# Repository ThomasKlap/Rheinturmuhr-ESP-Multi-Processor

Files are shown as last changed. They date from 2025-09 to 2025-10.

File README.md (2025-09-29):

#  Rheinturmuhr (Lichtzeitpegel) Düsseldorf  

Lichtzeitpegel ist die Bezeichnung der Uhrenlichtskulptur des Künstlers Horst H. Baumann am Düsseldorfer Rheinturm. Sie wurde am 24. November 1981 in Betrieb genommen und ist gemäß dem Guinness-Buch der Rekorde die größte dezimale „Zeitskala“ der Welt. Die Uhr wird auch als Dezimaluhr bezeichnet, obwohl der „Lichtzeitpegel“ die klassische 24-Stunden-Uhrzeit anzeigt und die Ziffern im Unärsystem dargestellt werden.  
[Quelle: Wikipedia, [Lichtzeitpegel]( de.wikipedia.org/wiki/Lichtzeitpegel )] 

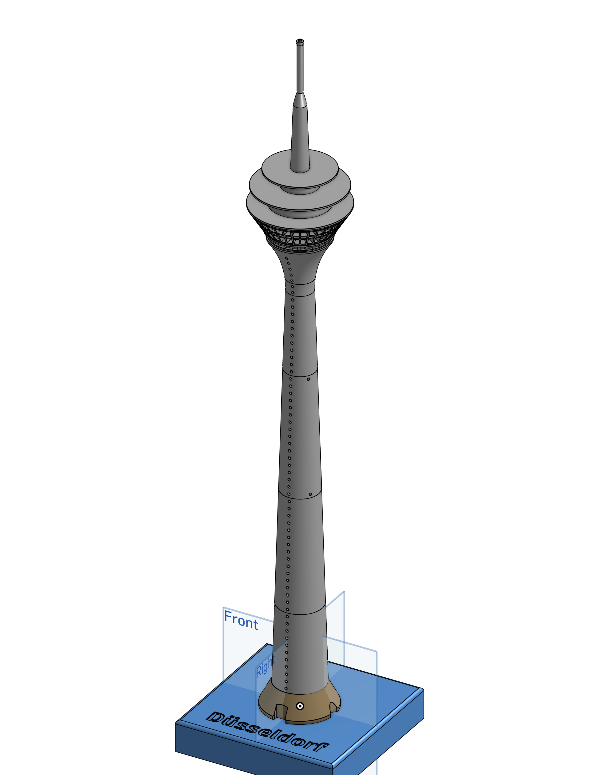
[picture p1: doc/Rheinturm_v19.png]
Bild


Die Bauteile, als .stl Files für den 3D Druck, liegen im Ordner Parts.  
Ich habe den Turm schon mehrfach in unterschiedlichen Farben PLA gedruckt.
Das Fenster oben im Restaurant sollte transparent gedruckt werden, da es von innen beleuchtet werden kann.
Zusätzlich zu den gedruckten Teilen wird eine Gewindestange M3x565 und zwei Gewindeeinsätze M3 benötigt, um den Turm zusammen zu halten.
Alternativ kann auch eine M4 Gewindestange direkt in die Kunststoffteile eingeschraubt werden.

Es wird ein 62 Elemente langer Neopixel Streifen, mit einer Dichte von 144px/m, verwendet.  
Dieser kann komplett in die Aufnahme innerhalb des Schaftes eingeführt werden.
Weitere Neopixel können oberhalb für das Restaurant verwendet werden.  
Die Positionsleuchten ringsum sind für 2mm Leds vorgesehen, welche dort eingeklebt werden.
Ich verwende für die Projekte einen Wemos D1mini mit ESP8266 Prozessor.  
Für den Anschluss wird ein 470 Ohm Widerstand empfohlen, um die Neopixel vor Spannungsspitzen zu schützen.

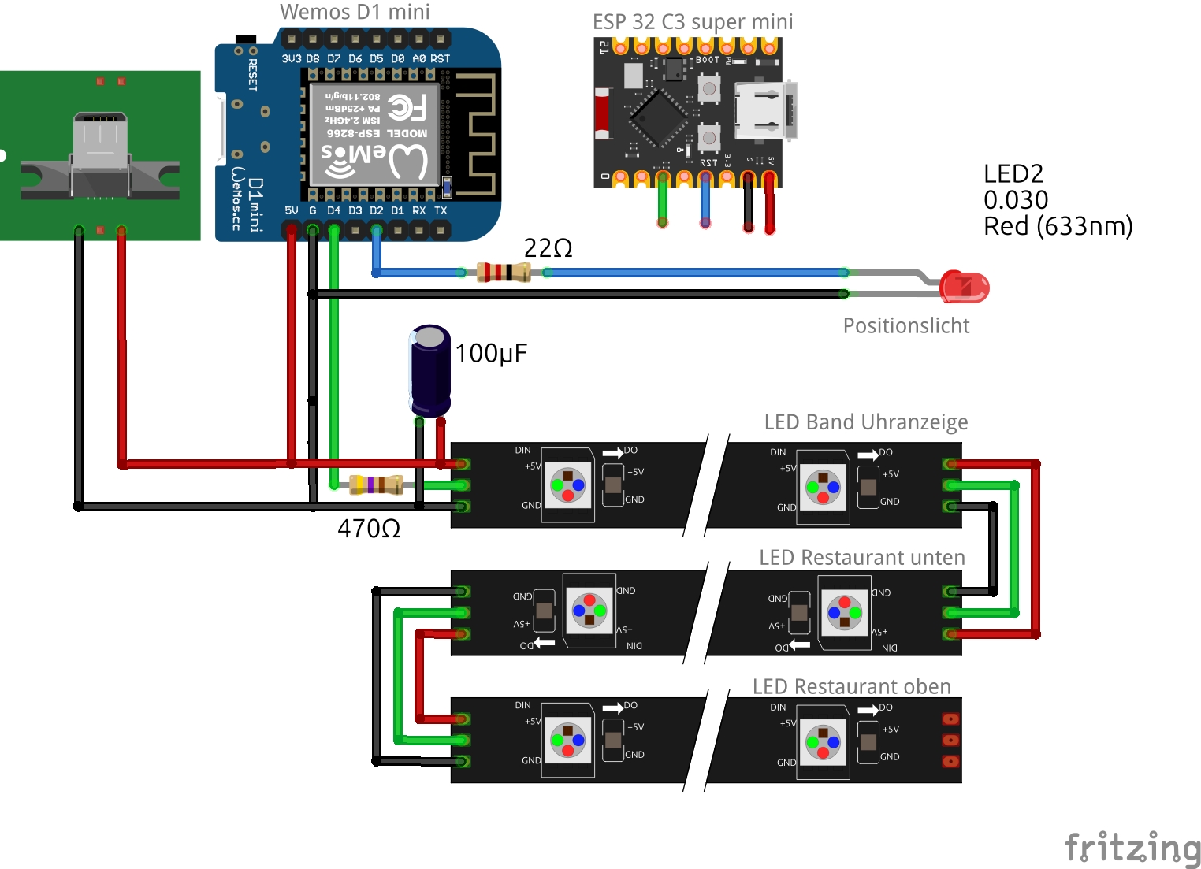
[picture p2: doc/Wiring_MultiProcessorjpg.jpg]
Schaltplan


Das Programm ist für einen Wemos D1 Mini kompiliert und kann aus dem Browser [Google Chrome oder Microsoft Edge] mittels ESP-WebTools installiert werden.  
[Link zu Web-Installation, mit ESP Web-Tools]( https://github.com/ThomasKlap/Rheinturmuhr-ESP-Multi-Processor/blob/main/flash.html )

Nach der Installation ist die Uhr als WLAN-Hotspot [Rheintrumuhr-VX_xxxx] verfügbar.  
Mit dem Kennwort [123456789] kann man sich mit Hotspot verbinden. Dann im Browser über die Adresse 192.168.4.1 des Parametermenue aufrufen und die lokalen WLAN Zugangsdaten eingeben. Ab dann bezieht die Uhr Ihrer Zeit selbständig via WLAN vom NTP Server [de.pool.ntp.org]

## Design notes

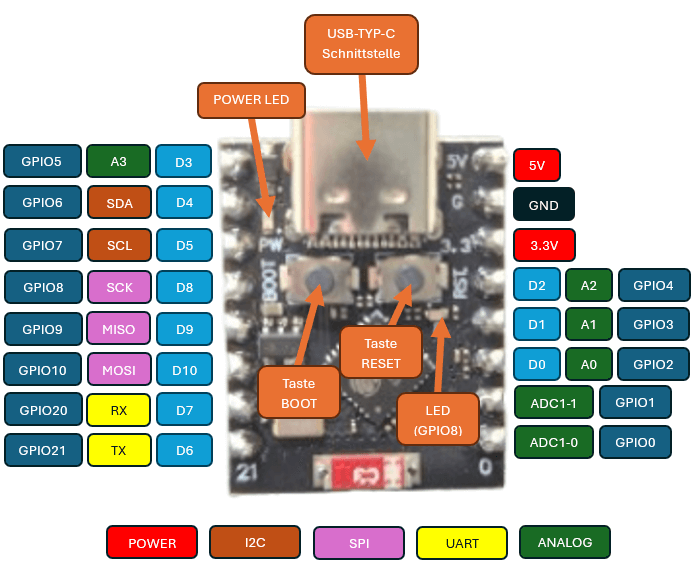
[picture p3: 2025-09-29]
doc/ESP32-C3-Pinout-2.png

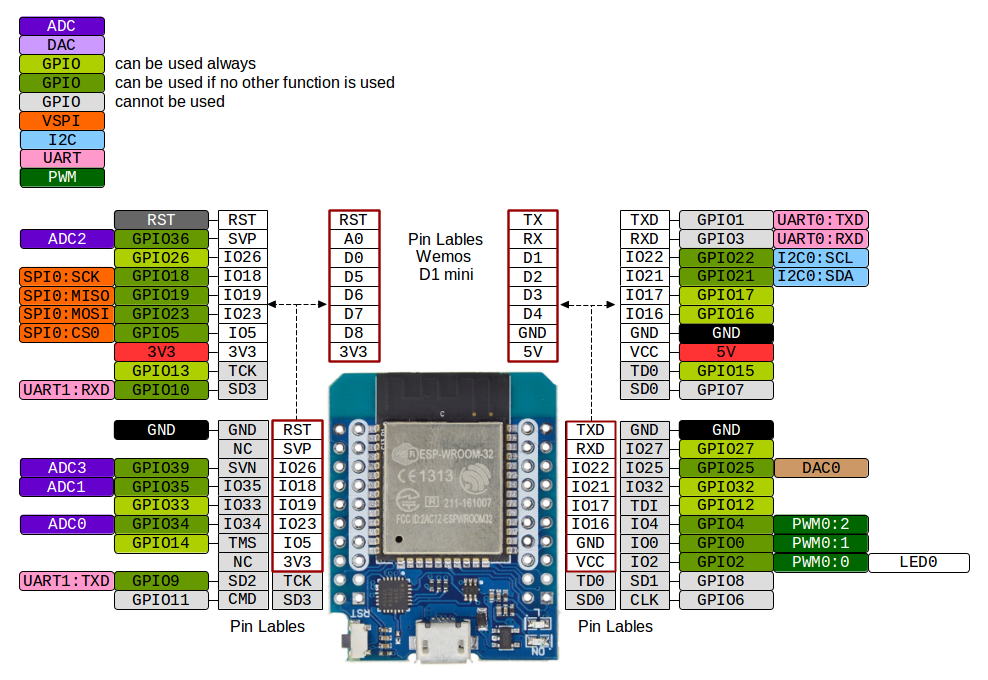
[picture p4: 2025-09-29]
doc/D1-MINI32 PinOut.png

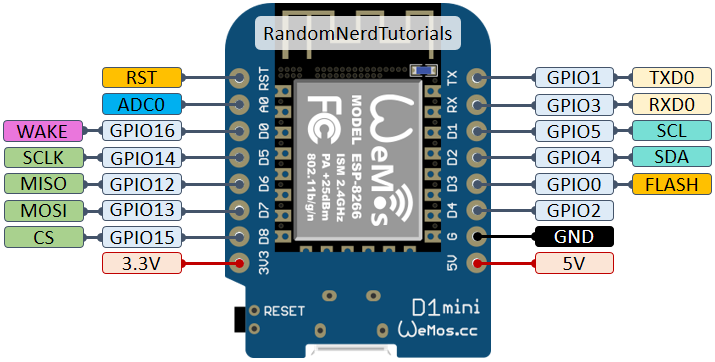
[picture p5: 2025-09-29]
doc/D1-MINI8266 PinOut.png

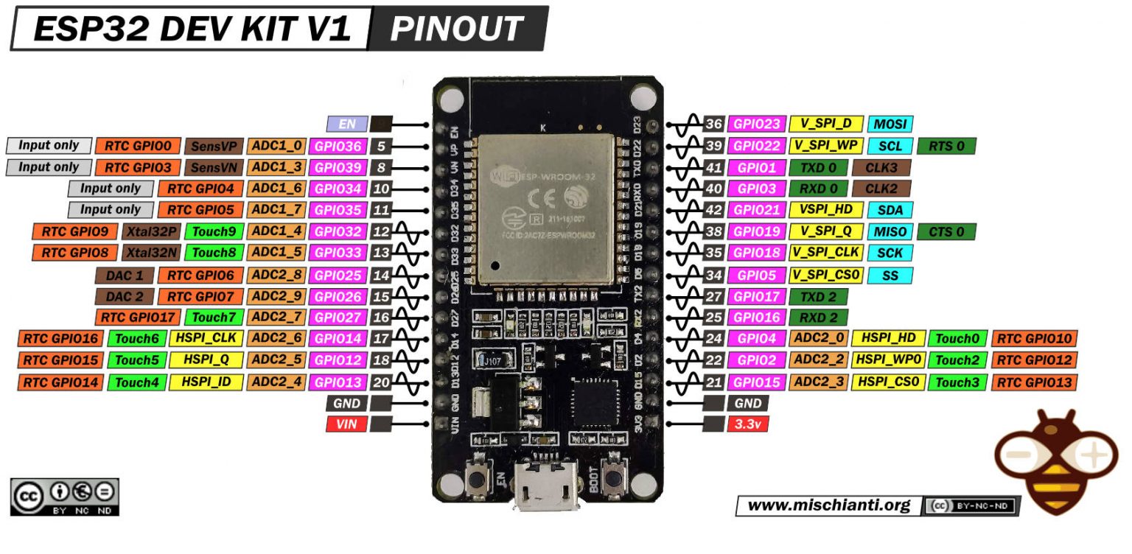
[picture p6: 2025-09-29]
doc/ESP32-PinOut.jpg

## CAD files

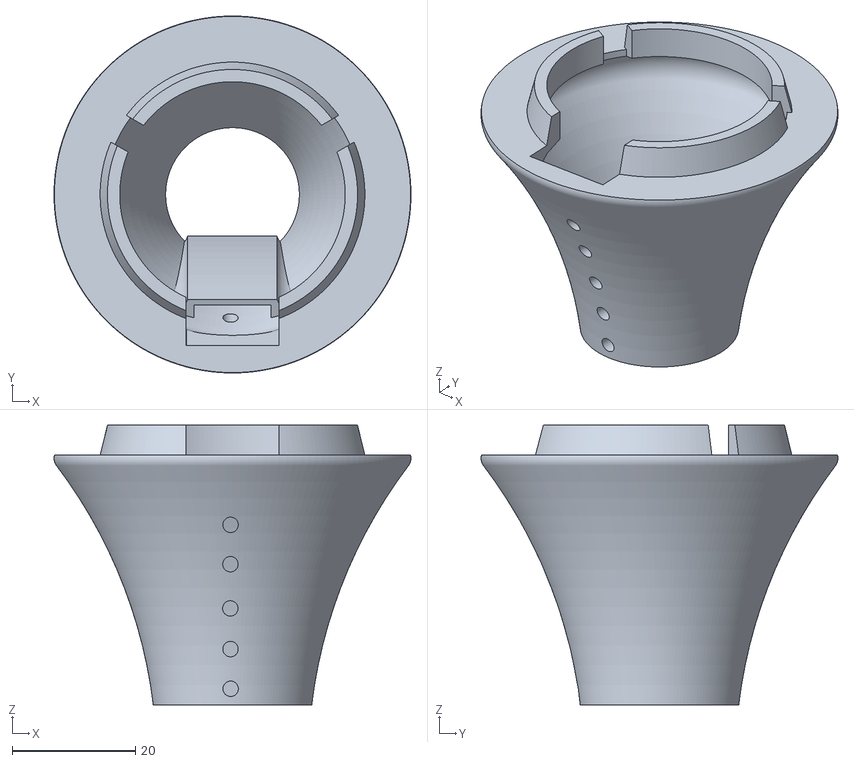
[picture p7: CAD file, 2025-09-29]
parts/Bauteile Rheinturm geschraubt NEU 2501 v19 - 06-Shaft-5.stl
57.9 x 57.9 x 45.3

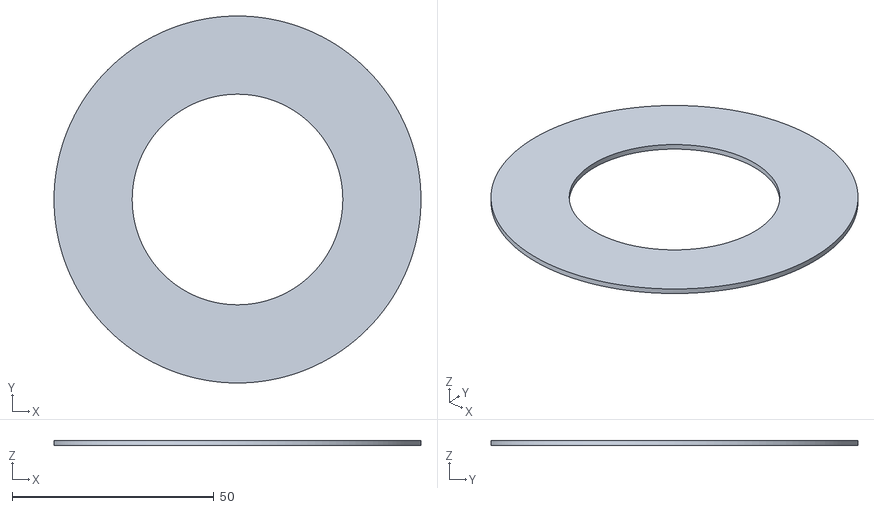
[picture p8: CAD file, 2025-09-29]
parts/Bauteile Rheinturm geschraubt NEU 2501 v19 - 09-Restaurant-3.stl
91.0 x 91.0 x 1.30

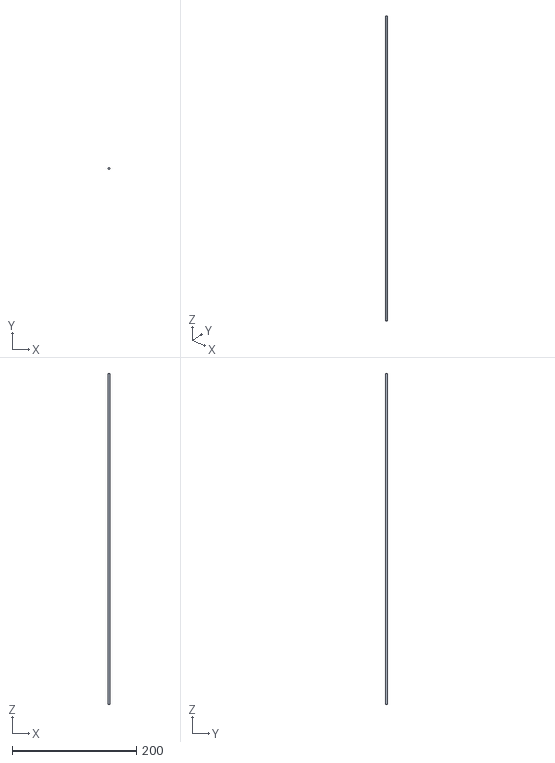
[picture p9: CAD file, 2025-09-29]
parts/Bauteile Rheinturm geschraubt NEU 2501 v16 parts - Gewindestange M3x535.stl
3.00 x 3.00 x 532.5

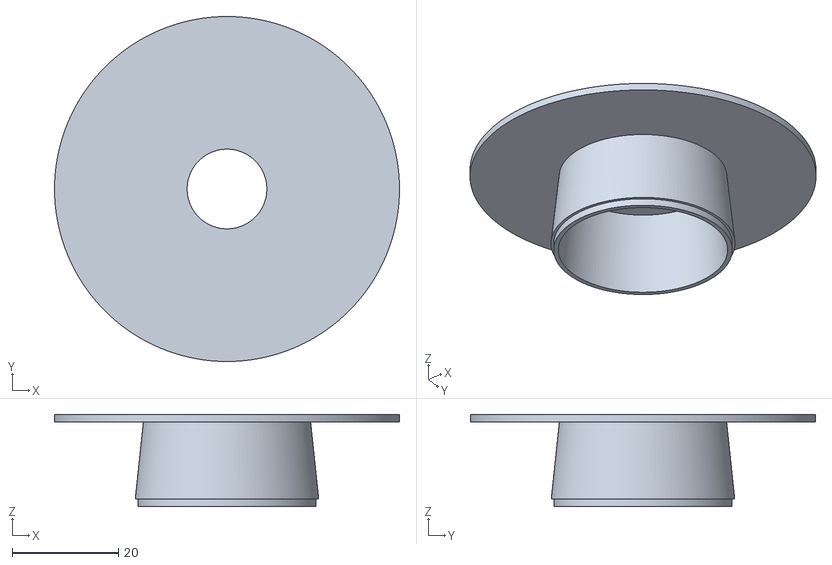
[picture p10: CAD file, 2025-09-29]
parts/Bauteile Rheinturm geschraubt NEU 2501 v19 - 11-Top-2.stl
64.9 x 64.9 x 17.3

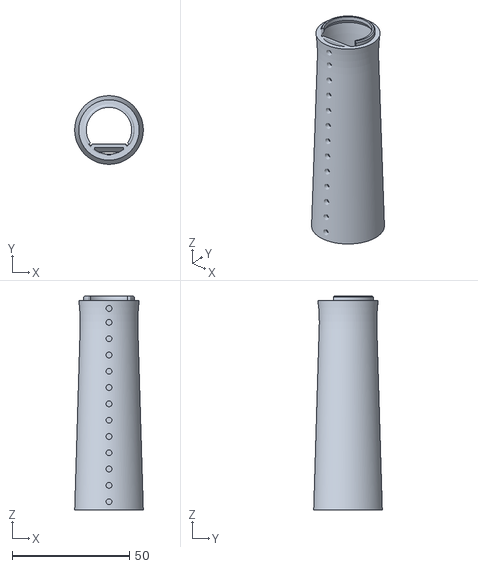
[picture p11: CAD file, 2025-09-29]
parts/Bauteile Rheinturm geschraubt NEU 2501 v19 - 05-Shaft-4.stl
29.2 x 29.2 x 91.1

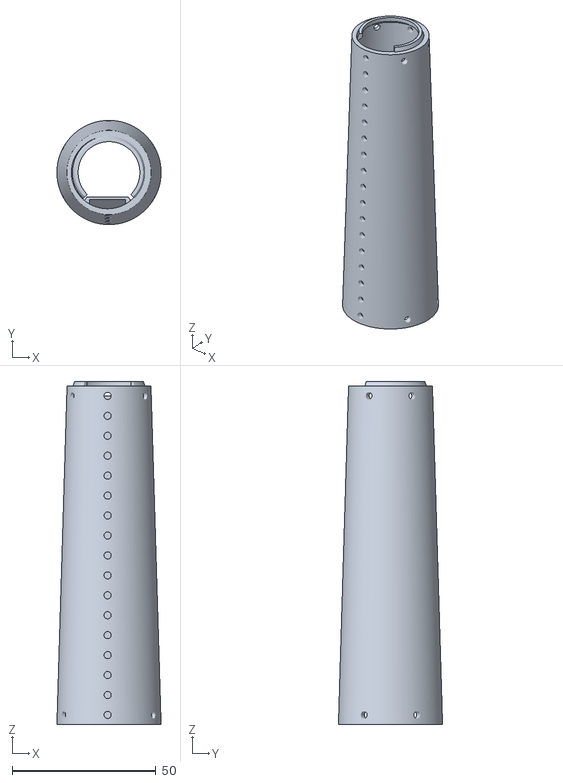
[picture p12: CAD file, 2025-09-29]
parts/Bauteile Rheinturm geschraubt NEU 2501 v19 - 04-Shaft-3.stl
36.3 x 36.3 x 119.4

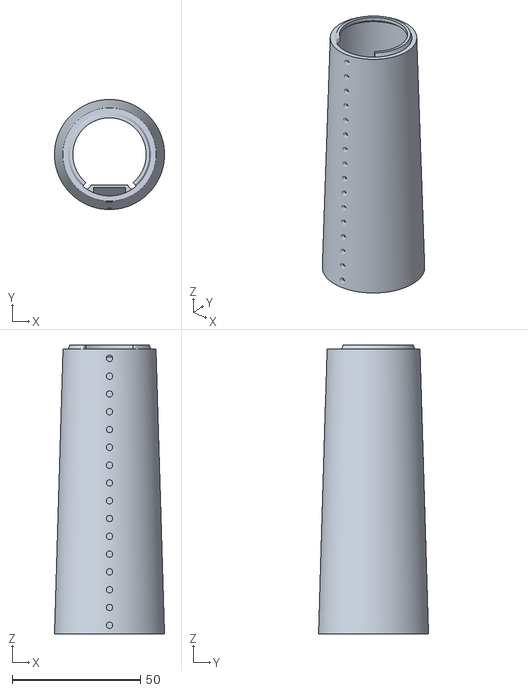
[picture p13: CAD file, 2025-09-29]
parts/Bauteile Rheinturm geschraubt NEU 2501 v19 - 03-Shaft-2.stl
42.9 x 42.9 x 112.7

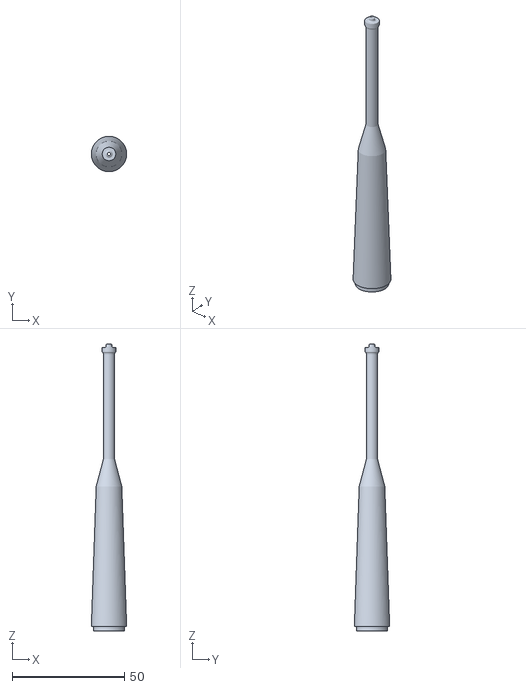
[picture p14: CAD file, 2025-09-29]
parts/Bauteile Rheinturm geschraubt NEU 2501 v16 parts - 13-TopPart-3.stl
15.8 x 15.8 x 127.9

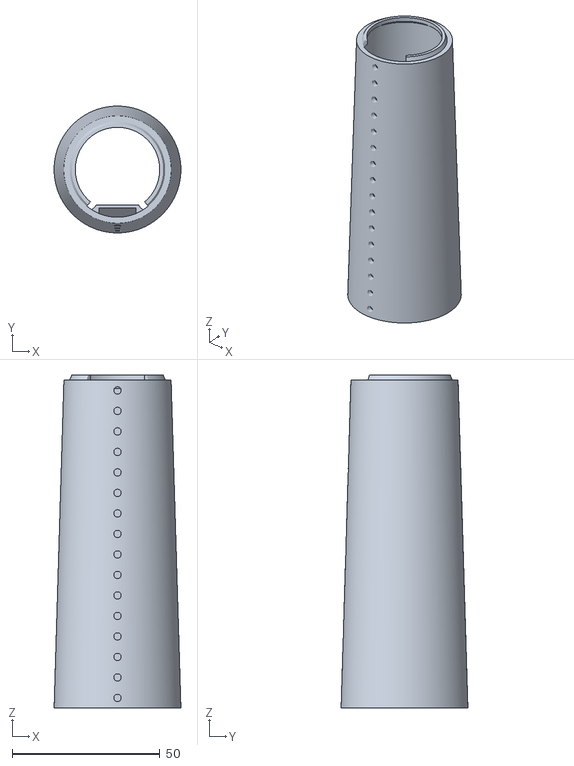
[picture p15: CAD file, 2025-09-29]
parts/Bauteile Rheinturm geschraubt NEU 2501 v16 parts - 04-ShaftPart-2.stl
42.9 x 42.9 x 112.7

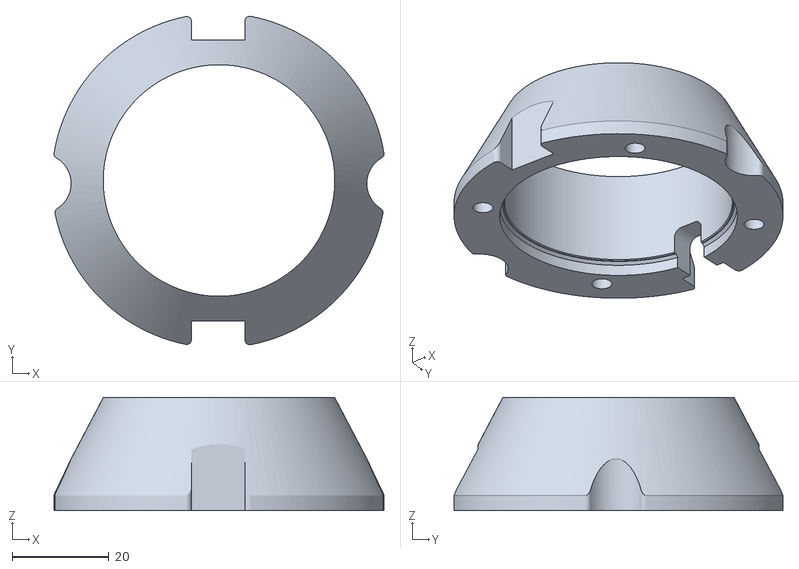
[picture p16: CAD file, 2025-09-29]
parts/Bauteile Rheinturm geschraubt NEU 2501 v19 - 01-Socket.stl
68.4 x 68.1 x 23.4

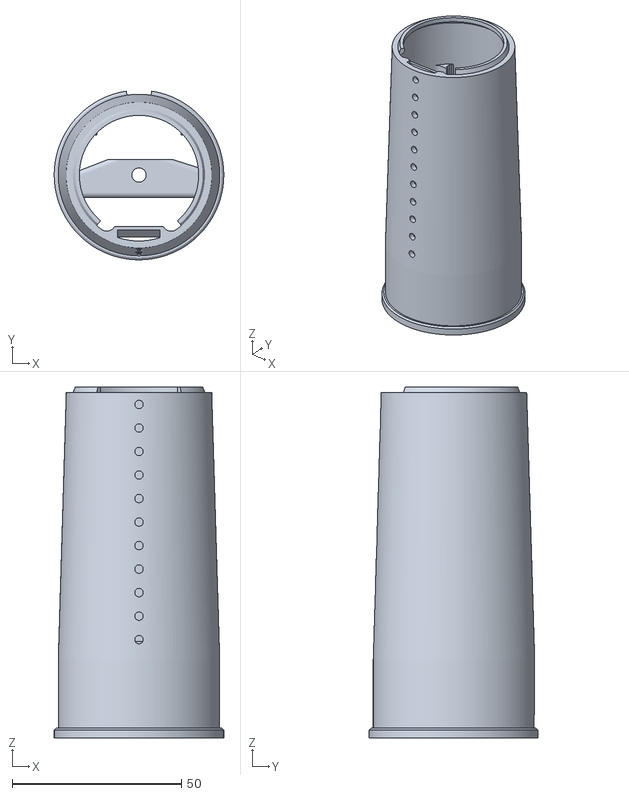
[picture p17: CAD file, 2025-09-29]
parts/Bauteile Rheinturm geschraubt NEU 2501 v16 parts - 03-ShaftPart-1.stl
50.1 x 49.8 x 103.6

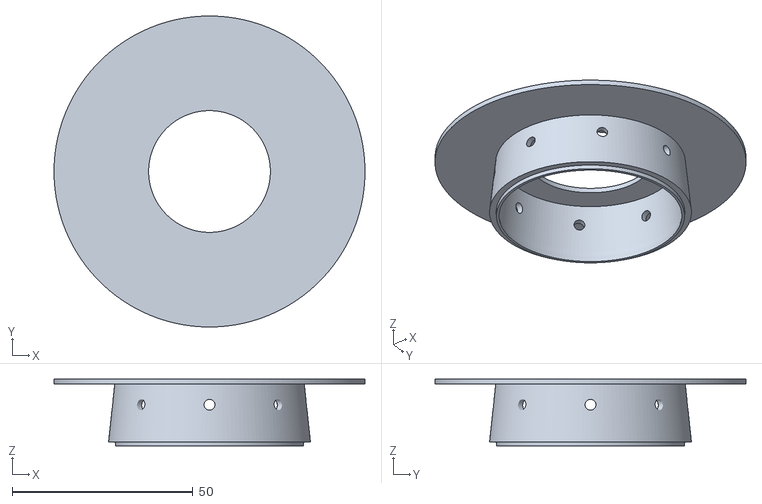
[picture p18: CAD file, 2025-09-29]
parts/Bauteile Rheinturm geschraubt NEU 2501 v19 - 10-Top-1.stl
86.0 x 86.0 x 18.5

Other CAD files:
parts/Bauteile Rheinturm geschraubt NEU 2501 v16 parts - 06-ShaftPart-4.stl
parts/Bauteile Rheinturm geschraubt NEU 2501 v16 parts - 05-ShaftPart-3.stl
parts/Bauteile Rheinturm geschraubt NEU 2501 v16 parts - 07-ShaftPart-5.stl
parts/Bauteile Rheinturm geschraubt NEU 2501 v16 parts - 08-Restaurant.stl
parts/Bauteile Rheinturm geschraubt NEU 2501 v16 parts - 09-RestaurantWindow.stl
parts/Bauteile Rheinturm geschraubt NEU 2501 v19 - 02-Shaft-1.stl
parts/Bauteile Rheinturm geschraubt NEU 2501 v19 - 07-Restaurant-1.stl
parts/Bauteile Rheinturm geschraubt NEU 2501 v19 - 08-Restaurant-2.stl

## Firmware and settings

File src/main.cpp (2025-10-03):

#include "main.h" // move all definitions to separate header-include

#define PROGRAM_VERSION "v7.1.0"
#define BUILD_DATE __DATE__ " " __TIME__



void npx_start() 
{ 
  pixels.begin(); // INITIALIZE NeoPixel strip object (REQUIRED)
  pixels.clear(); // Set all pixel colors to 'off'
  pixels.show();   // Send the updated pixel colors to the hardware.
} ;



// Funktion zur Anzeige Starrer Lichter
void shiftout_light (int startpos, int bits, int color_red, int color_green, int color_blue)   // Parameter übernehmen
{ for (int i = 0; i < bits; i++) {
    pixels.setPixelColor(startpos + i, pixels.Color(color_red, color_green, color_blue));
    //pixels.show(); // This sends the updated pixel color to the hardware.
    yield(); // Gebe dem System Zeit für Hintergrundaufgaben
  }
}

// Funktion zur Anzeige Stellenzaehler
void shiftout_bits (int startpos, int bits, int value, int color_red, int color_green, int color_blue)   // Parameter übernehmen
{ for (int i = 0; i < bits; i++) // Hauptschleifenzähler, Anzahl der auszugebenden Bits
  { if (value > i) //Wert ist größer als Schleifenzähler
    { 
      pixels.setPixelColor(startpos + i, pixels.Color(color_red, color_green, color_blue)); //send Bit out
      //pixels.show(); // This sends the updated pixel color to the hardware.
      //delay(delayval); // Delay for a period of time (in milliseconds).
    }
    else // Aktion bei Low Bit
    { pixels.setPixelColor(startpos + i, pixels.Color(0, 0, 0)); //send Bit out
      //pixels.show(); // This sends the updated pixel color to the hardware.
      //delay(delayval); // Delay for a period of time (in milliseconds).
    }
    yield(); // Gebe dem System Zeit für Hintergrundaufgaben
  }
  // pixels.show();
  //return; // Funtion wieder verlassen
}


// Funktion zur Anzeige der Restaurantlichter
void rest_light(int startpos, int bits, int color_red, int color_green, int color_blue) //Anzeige der Restaurant LichterWechselnd
{
unsigned long currentMillis = millis(); // Aktuelle Zeit wird in currentMillis gespeichert

  if (currentMillis - RestMillis >= intervalRestMillis) { // Falls mehr als 1000 ms vergangen sind
      shiftout_light (startpos, bits, color_red, color_green, color_blue);

  }
  if (currentMillis - RestMillis >= intervalRestMillis*2) { // Falls mehr als 1000 ms vergangen sind
      shiftout_light (startpos, bits, color_red/2, color_green/2, color_blue/2);
     RestMillis = currentMillis;} // Zeitpunkt der letzten Schaltung wird festgehalten 
    
  // pixels.show();   // Send the updated pixel colors to the hardware.
}

// Funktion zur Anzeige der Positionslichter
void pos_light(int startpos, int bits, int color_red, int color_green, int color_blue) //Anzeige der Positionsleuchten Blinkend
{
unsigned long currentMillis = millis(); // Aktuelle Zeit wird in currentMillis gespeichert

  if (currentMillis - PosMillis >= intervalPosMillis) { // Falls mehr als 1000 ms vergangen sind
      shiftout_light (startpos, bits, color_red, color_green, color_blue);
      digitalWrite(PosLedPin, HIGH); 
      
      
  }
  if (currentMillis - PosMillis >= intervalPosMillis*2) { // Falls mehr als 1000 ms vergangen sind
      shiftout_light (startpos, bits, 0, 0, 0);
      digitalWrite(PosLedPin, LOW); 
      
      
     PosMillis = currentMillis;} // Zeitpunkt der letzten Schaltung wird festgehalten 
    
  // pixels.show();   // Send the updated pixel colors to the hardware.
}

// Funktion zur Ausgabe der gesamten Anzeige zum Turm
void show_out(int sec, int min, int hrs) 
{
  shiftout_light (0, 11, emptyR, emptyG, emptyB); // die ersten 11 Stellen Trenner in Gelb
  
  //sekunden Einerstelle ausgeben
  tempNPX = sec % 10 ;
  shiftout_bits(11, 9, tempNPX, countR, countG, countB); // Funktion Bitszählen und Muster ausgeben aufrufen
  // Trennstelle ausgeben
  shiftout_light(20, 1, spaceR, spaceG, spaceB); // einzelne Lampe
  //sekunden Zehnerstelle ausgeben
  tempNPX =  sec/ 10 ;
  shiftout_bits(21, 5, tempNPX, countR, countG, countB); // Funktion Bitszählen und Muster ausgeben aufrufen

  // Trennstellen ausgeben
  shiftout_light(26, 2, spaceR, spaceG, spaceB); // einzelne

  //minutenen Einerstelle ausgeben
  tempNPX = min % 10 ;
  shiftout_bits(28, 9, tempNPX, countR, countG, countB); // Funktion Bitszählen und Muster ausgeben aufrufen
  // Trennstelle ausgeben
  shiftout_light(37, 1, spaceR, spaceG, spaceB); // einzelne Lampe
  //minuten Zehnerstelle ausgeben
  tempNPX = min / 10 ;
  shiftout_bits(38, 5, tempNPX, countR, countG, countB); // Funktion Bitszählen und Muster ausgeben aufrufen

  // Trennstelle ausgeben
  shiftout_light(43, 2, spaceR, spaceG, spaceB); // einzelne
  //stunden Einerstelle ausgeben
  tempNPX = hrs % 10 ;
  shiftout_bits(45, 9, tempNPX, countR, countG, countB); // Funktion Bitszählen und Muster ausgeben aufrufen
  // Trennstelle ausgeben
  shiftout_light(54, 1, spaceR, spaceG, spaceB); // einzelne Lampe
  //stunden Zehnerstelle ausgeben
  tempNPX = hrs / 10 ;
  shiftout_bits(55, 2, tempNPX, countR, countG, countB); // Funktion Bitszählen und Muster ausgeben aufrufen
  // Leere Stellen ausgeben
  shiftout_light(57, 5, emptyR, emptyG, emptyB); // fuenf Trennstellen
  // Restuarantbeleuchtung
  rest_light(62,18,restR, restG, restB); // Restaurantbeleuchtung
  
  pos_light (75,8,restR, restG, restB); 
  pixels.show();
}


void setup()
{
  pinMode(PosLedPin, OUTPUT); // Setzt den Digitalpin als Outputpin
  
  Serial.begin(115200);
  delay(1000); // wait a while
  npx_start(); // Start Routine für die Neopixel
    shiftout_light(0, 2,spaceR, spaceG, spaceB); // zwei rote für start
    pixels.show();
    delay(500); // wait a while

  // Ausgabe der Programmversion und des Build-Datums
  Serial.println(" ");
  Serial.println("-------------------------------");
  Serial.println("Rheinturmuhr-ESP Multiprocessor ");
  Serial.println("-------------------------------");
  Serial.println(" ");
  Serial.print("Programmversion: ");
  Serial.print(PROGRAM_VERSION);
  Serial.print("\t Build-Datum: ");
  Serial.println(BUILD_DATE);
  Serial.print("MAC-Adresse: ");
  Serial.println(WiFi.macAddress());
  Serial.print("Saved-WLAN SSID: ");
  Serial.println(WiFi.SSID());
  Serial.print("Saved-WLAN Passwort: ");
  Serial.println(WiFi.psk());
  delay(500); // wait a while

  WiFiManager wm;
  bool res;
  //res = wm.autoConnect("Turmuhr" PROGRAM_VERSION, apPwd); // password protected ap
  res = wm.autoConnect(apSsid, apPwd); // password protected ap --- IGNORE ---
  if (!res)
  {
    Serial.println("Failed to connect");
    // ESP.restart();
    shiftout_light(0, 4,spaceR, spaceG, spaceB); // vier rote für start
    pixels.show();
    delay(500); // wait a wihle
  }
  else
  {
    // if you get here you have connected to the WiFi
    Serial.println("connected...yeey :)");
    shiftout_light(0, 6,spaceR, spaceG, spaceB); // sechs rote OK
    pixels.show();
    delay(500); // wait a wihle
  }

  configTime(0, 0, NTP_SERVER);
  setenv("TZ", TZ_INFO, 1);
  shiftout_light(0, 6,spaceR, spaceG, spaceB); // sechs rote für start fertig
  pixels.show();
  delay(1000); // wait a while
  Serial.println("NTP Zeit empfangen");
  delay(1000); // wait a while
  time(&now);             // Liest die aktuelle Zeit
  localtime_r(&now, &tm); // Beschreibt tm mit der aktuelle Zeit
  Serial.print(wochentage[tm.tm_wday]);
  // Serial.print(tm.tm_wday);         // Wochentag als Zahl, 0 = Sonntag
  Serial.print("\tder ");
  Serial.print(tm.tm_mday);
  Serial.print(" " + monat[tm.tm_mon] + " ");
  Serial.print(tm.tm_year + 1900);

  Serial.printf(" \tUhrzeit: %02d:%02d:%02d \n", tm.tm_hour, tm.tm_min, tm.tm_sec);
    shiftout_light(0, 8,spaceR, spaceG, spaceB); // acht rote für start fertig
    pixels.show();
    delay(1000); // wait a while
}

void loop()
{

  delay(200);
  /* Zykluszeit messen
  CycleMillis = millis();
  
  CycleMillis = millis() - CycleMillis;
  
  Serial.print("CycleTime: ");
  Serial.println(CycleMillis);
  
  */ // Zykluszeit messen Ende


  delay(100);
  time(&now);             // Liest die aktuelle Zeit
  localtime_r(&now, &tm); // Beschreibt tm mit der aktuelle Zeit
  delay(100);
  show_out(tm.tm_sec, tm.tm_min, tm.tm_hour); // send lights to the NPX Stripe  
}

// Ende main.cpp

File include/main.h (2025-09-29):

#include <Arduino.h>
#include <WiFiManager.h>
#include <time.h>
#include <Adafruit_NeoPixel.h>


const char *apSsid = "RheinturmuhrV7"; // SSID for AP if WLAN failed ; replaced with PROGRAM_VERSION
const char *apPwd = "123456789"; // SSID for AP if WLAN failed and first setup


int lastMilis;
int temp;
unsigned long CycleMillis = 0; // milli secounds conuter for cyclic delay funtions
const char *NTP_SERVER = "de.pool.ntp.org";
const char *TZ_INFO = "CET-1CEST-2,M3.5.0/02:00:00,M10.5.0/03:00:00";

char wochentage[7][12] = {"Sonntag", "Montag", "Dienstag", "Mittwoch", "Donnerstag", "Freitag", "Samstag"};
String monat[12] = {"Januar", "Februar", "März", "April", "Mai", "Juni", "Juli", "August", "September", "Oktober", "November", "Dezember"};

time_t now;
struct tm tm;

/*Farbendefinitionen für die Ausgabe zu Turm
Definition der Pixel:
Adresse 0-10 ohne Funktion, standard Gelb
Adresse 11-20 Sekunden 1" Stelle
.....
*/
int emptyR =7; //Leere Segmente
int emptyG =7;
int emptyB =0;

int spaceR =10; // Trenner
int spaceG =0;
int spaceB =0;

int countR =0; //Zaehler
int countG =0;
int countB =30;

int posR =50; //Positionslichter
int posG =0;
int posB =0;

int restR =00; //Restaurant
int restG =10;
int restB =10;

#define NeoPixelPin   2// 
#define PosLedPin     4 // GPIO  for Position LED 
#define NUMPIXELS 86 // how many neopixels where attached

unsigned long PosMillis = 0; // time counter for position lights with millis() function
const long intervalPosMillis = 900; // light intervall for the position lights

unsigned long RestMillis = 0; // time counter for position lights with millis() function
const long intervalRestMillis = 2000; // light intervall for the position lights

int tempNPX = 0; // temporary variable

Adafruit_NeoPixel pixels(NUMPIXELS, NeoPixelPin, NEO_GRB + NEO_KHZ800);

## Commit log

2025-09-29 ausgabe zu den NPX nur einmal am ende der Funktion.
2025-09-29 Dokumentation angepasst
    [Wiring.fzz]
2025-09-29 weitere Korrekturen an der Dokumentation
2025-09-29 Links in der DOC korrigiert
2025-09-29 kleine Anpassungen---> Probleme it ESP32C3superMini
    [Wiring.fzz]
